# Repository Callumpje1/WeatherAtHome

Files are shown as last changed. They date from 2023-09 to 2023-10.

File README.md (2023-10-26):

# Weather at Home

Web application for displaying current climate data which is measured with a Wemos D1 Mini.

## Features

- Display current temperature and Humidity
- Add weather data for a given location
- Remove weather data for given location
- Plot chart for historic weather data
- Change temperature range via http

## Screenshots

### Homepage
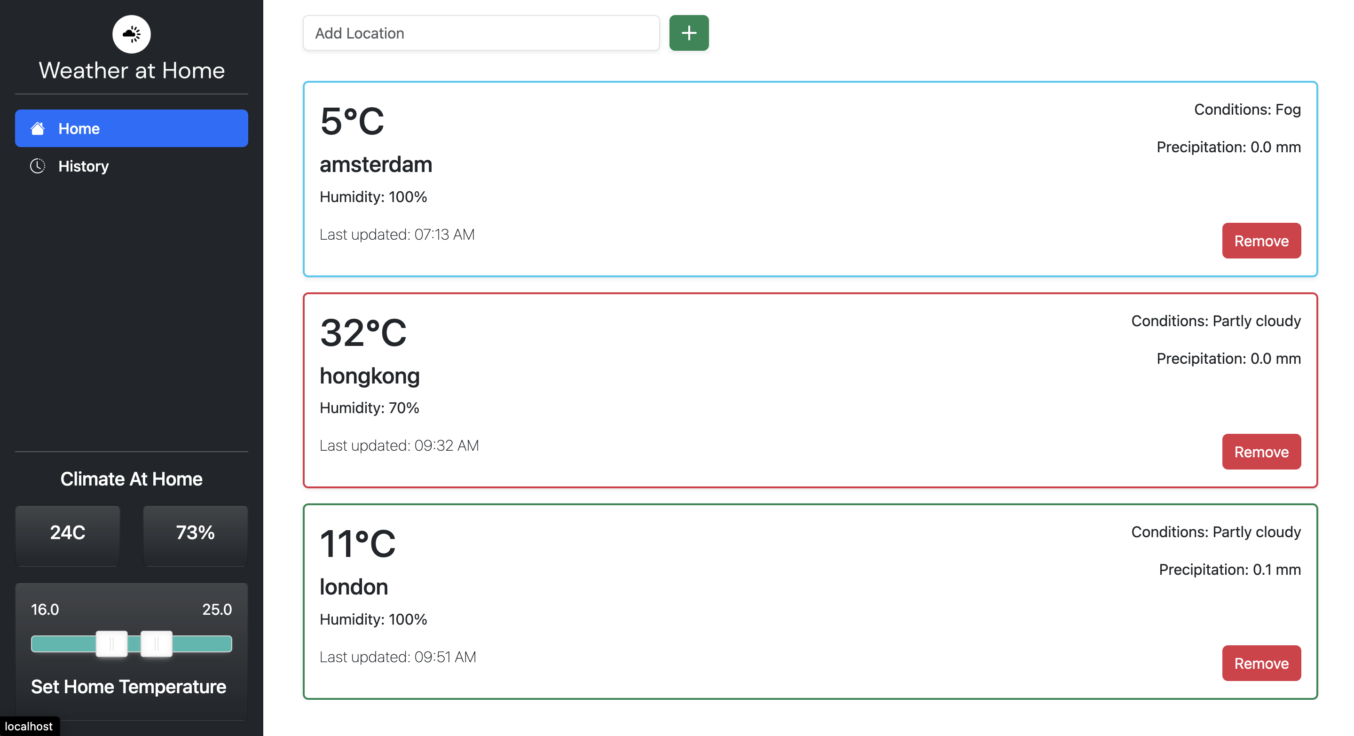
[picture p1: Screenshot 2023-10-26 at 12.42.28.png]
Homepage


### History
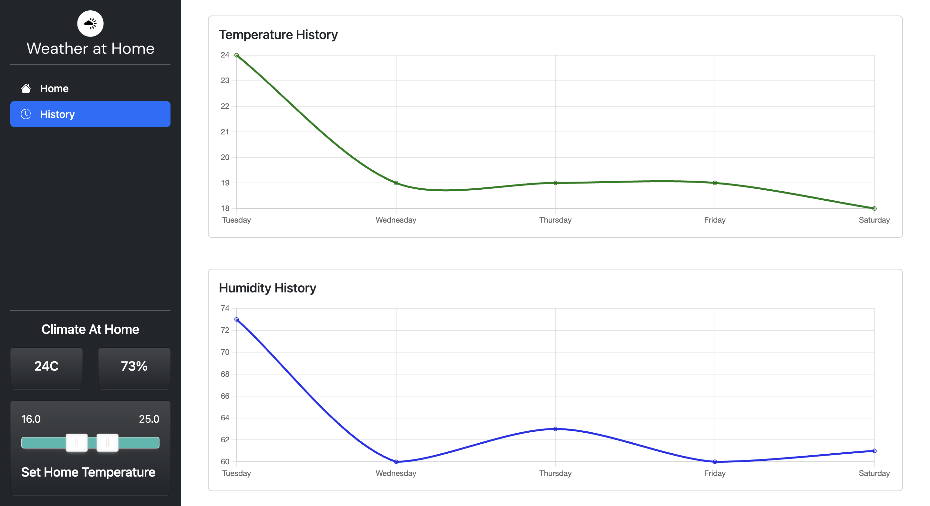
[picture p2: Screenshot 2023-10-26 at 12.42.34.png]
History


## Tech Stack

**Client:** C++ and Javascript

**Server:** Php

## Authors

- [@Callumpje1](https://www.github.com/Callumpje1)

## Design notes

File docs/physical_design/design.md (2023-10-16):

# Design

## Concept

### User and User Needs

At first i had chosen to make a star-wars themed weather station to appeal to the millions of star-wars fans around the world. However this concept showed to be a lot more complex to create then expected at first and didn't seem to work out the way i wanted it to. It was very hard to create a clear yoda character that would into eachtother without any glue. Due to these complications i chose to completely change my design.

Amsterdam, the city where i was born and where i have lived all my life. The city center has one thing that really stands out and is loved by most inhabitants of Amsterdam, the canal houses! These housed were built in the 17th century and where used for residences, storage units, and business during the dutch Golden Age. Nowadays these houses are some of the most expensive in the city meaning only the ultra rich can enjoy the design and heritage of the canal houses.
That's why i chose to create a weather station that resembles an Amsterdam canal house. This way anyone can own a small version of their favourite canal house at home.

### Goals of the Product

The goal of the product is to give everyone who loves the Amsterdam canal houses a chance to own their own one. This mini version is not only relevant due to the design that resembles the canal houses. A lot of the houses in Amsterdam, especially the older ones, don't have a reliable thermometer that gives the homeowners the information they need to be able to live in a comfortable temperature. That's why i chose to turn this mini canal house into a weather station. This weather station will give users the real-time temperature and humidity in their house. These values can be read out from a lcd screen by pressing a button. Next to the lcd screen the house will also have a led light which will give the user a color based on the temperature inside. This led light will change to red if it is too hot inside, green if the temperature is just right and blue when it's too cold inside.

### Requirements

In the below image you will see the requirements that i have set up for the physical design. The requirements contain some that are specific for the user that will use the product and some that are specific to the manufacturer of the product.

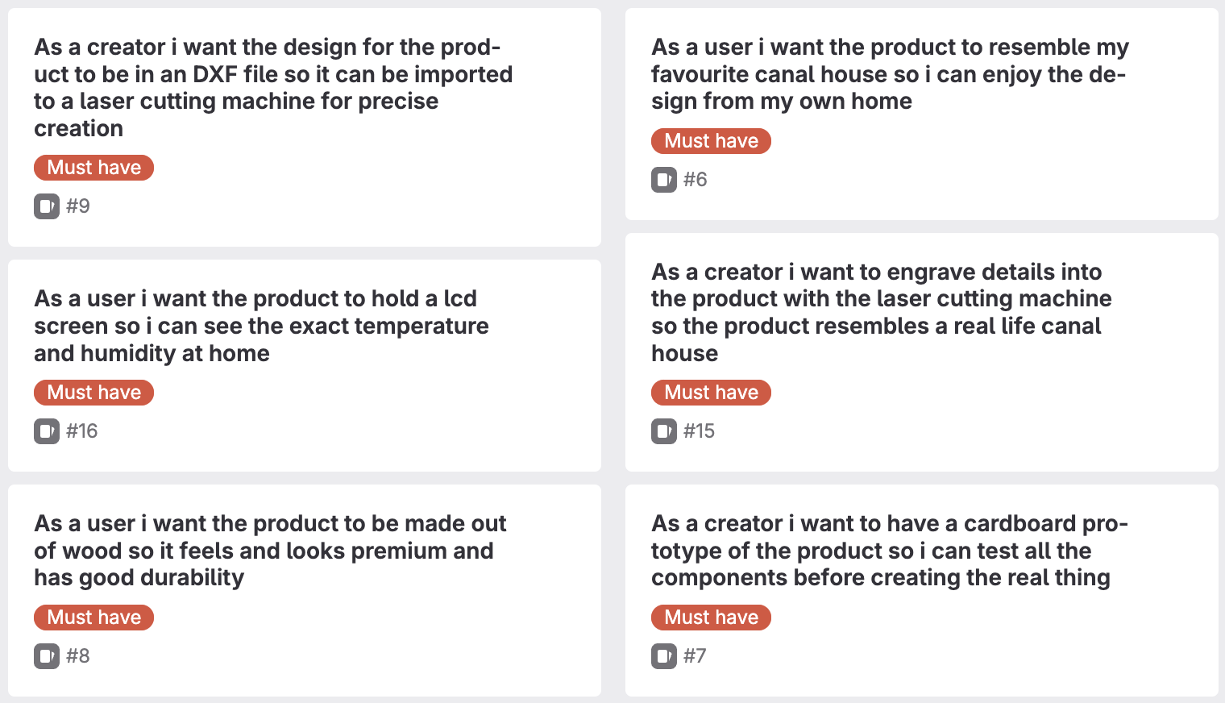
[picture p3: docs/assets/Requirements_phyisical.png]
Requirements Board Physical Design


### Sketches

Below you will find the sketch i created to get an idea for how the product will look. In the sketch i decided to draw the overall look of the house aswell as how the laser cut should look to be able to fit the parts together. The front face of the house will hold the lcd screen and button to control the screen for energy saving purposes. The display itself will display the current temperature and humidity within the users home. The top front of the house will have a windowd which will hold a rgb led. This led will change color based on the temperature. The color of the led will indicate that the user may need to decrease or increase the temperature in their home. The top of the box itself will have 4 slots that will be used to attach the roof. The slots will have a width of 5mm, this is the same thickness as the wood i want to use for the product. The sketch also shows some details like the shield at the top of the house and the front door. These details will be engraved into the product to give a premium and detailed look to the house.

 In the paper prototype i printed out the dxf version of my design to get an idea for how all the parts will fit into eachtother. After printing and cutting out the design i realised that i needed to be more precise when creating the slots for the roof. After this i made some changes to my dxf design in Inkscape to make the parts fit into eachtother perfectly.

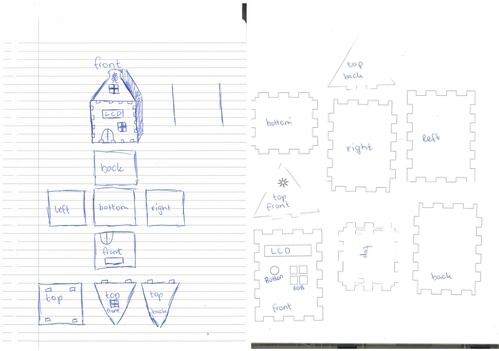
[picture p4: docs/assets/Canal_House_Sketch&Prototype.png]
Canal House Sketch & Paper Prototype


## Digital Manufacturing

### The Device

To create my desired design i will be using the BRM 6090 laser cutter which is available to us at the maker's lab. This machine has the possibility to cut and engrave materials with extreme precision. This machine keeps track of the material you are using and cuts accordingly, no need for measuring the distance of the laser to the material you are cutting. This makes it a lot easier to cut and engrave after eachother without changing the setup myself.

### The Material

I have chosen to create the canal house with 5mm mdf wood. I have chosen this material because it has a premium feel to it and i want my product to resemble the canal houses which are very expensive in real life. Also the material is very smooth and easy to work with. In my final design i don't only want to cut using the laser cutter, i also want to engrave and perhaps paint the surface so it comes as close as possible to a real canal house. For all these applications this wood suits the best. Also this wood fits together well when a right KERF is used to cut, this way the house can be assembled without glue.

## Digital Design

To Design the canal house i decided to first draw a sketch so i could get an idea of how i would create it. The first sketch is displayed in Sketches in a previous paragraphs. After drawing the sketch i decided to create a first prototype with paper to see if my design would work. To create the first prototype i used the Inkscape, this software is easy to use and can save a design in many file types that are supported by the laser cutting software: Lasercut. After recreating my sketch in Inkscape i printed the design on a A4 paper and cut it out to see if the concept would work. The paper prototype seemed like it would work. Because of this i decided to go to the Makerslab and laser cut the design to see what it would look. When laser cutting the design i realised that there were a couple of issues with my initial design. The way i had decided to create the house was not going to make it possible to attach a roof easily, which is essential for my design to work with the embedded device's LED. I had also not calculated the KERF of the machine correctly which meant the parts didn't fit together properly.

First design iteration

When creating the second iteration of my design i knew that i had to come up with a better way to design the roof and that i had to apply the right amount of KERF to make the pieces fit together seamlessly without glue.
So in my final iteration i created a different version of the roof by placing a inkscape node in the middle of my house and extending it to make a point that would resemble the roof, the roof has 2 finger slots to place the roof panels onto. I then measured the depth of the house to create the roofpanels with 2 slots on each side to connect to the slots in the house. By doing this i knew the roof would fit without too much effort.
In this iteration i also decided to place the window higher in the house to spread all components and make it feel more like a real house. When i started laser cutting my design i needed a couple of tries to figure out what the kerf of the laser cutter was. After doing a couple of miniature iterations and changing the thickness of the KERF i came to the conclusion that i needed to use a 0.400mm width to make the pieces fit together seamlessly

Couple of iterations

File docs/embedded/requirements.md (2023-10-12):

# Requirements

|Requirement ID#|Requirement|MoSCoW|Compliant|
|---|---|---|---|
|EMBRQ#01|Embedded device sends measured sensordata to the application backend over http or https.|Must|Yes|
|EMBRQ#02|Embedded device receives or retrieves status messages from the application backend over http or https.|Must|Yes|
|EMBRQ#03|Embedded device contains a dht-22 sensor to read temperature and humidity data|Must|Yes|
|EMBRQ#04|Embedded device contains a tactile button for switching the lcd's backlight on or off|Must|Yes|
|EMBRQ#05|Embedded device contains a rgb-module to display different colors based on the current temperature|Must|Yes|
|EMBRQ#06|Embedded device contains a 16x2 lcd for displaying current temperature and humidity|Must|Yes|
|EMBRQ#07|The embedded device uses the wifi manager for configuration of SSID, User ID (UID) en Password (PWD) for connecting to the network.|Must|Yes|

##EMBRQ#01
We start of with connecting to wifi with the ESP8266WiFi library by using our ssid and password. Then a variable is created for the endpoint in our php to which the data will be sent. We also add a delay timer so data is only sent once every 10 seconds. If the device connects to the wifi and is outside the timer delay we create a HTTP client using the ESP8266HTTPClient library. We then specify the content type to Json and create a JSON object with the temperature and humidity data which is collected from the temperature sensor. Then the json data is serialized into a JSON string and sent to the server via a HTTP POST request. 

Code:
```
#include <ESP8266WiFi.h>
#include <ESP8266HTTPClient.h>
#include <ArduinoJson.h>

const char *serverName = "http://rnuqm-145-28-186-143.a.free.pinggy.online/php/data_post.php";

unsigned long lastTime = 0;
unsigned long timerDelay = 10000;

void loop(){
  // Send an HTTP POST request every 10 seconds
  if ((millis() - lastTime) > timerDelay)
  {
    // Check WiFi connection status
    if (WiFi.status() == WL_CONNECTED)
    {
      WiFiClient client;
      HTTPClient http;

      // Domain name with URL path or IP address with path
      http.begin(client, serverName);

      // Specify content-type header
      http.addHeader("Content-Type", "application/json");

      // create a Json object
      DynamicJsonDocument doc(200);

      doc["temperature"] = dht.readTemperature();
      doc["humidity"] = dht.readHumidity();

      String jsonString;
      
      // Serialize the Json object
      serializeJson(doc, jsonString);

        // Post Json object to server
      http.POST(jsonString);

      // Disconnect
      http.end();
    }
    else
    {
      Serial.println("WiFi Disconnected");
    }
    lastTime = millis();
  }
}
```

##EMBRQ#02

[Insert text explaining how you fulfilled the requirement here]

Code:

##EMBRQ#03
Fulfilling this requirement was quite straightforward. We first include the DHT library and define the type of our dht sensor, which in my case is the dht22 and define the pin to which the sensor is connected. We then begin reading from the sensor with dht.begin(). In the loop we read the temperature and humidity from the sensor with the dht.readTemperature() or .readHumidity() functions. The functions inside the library already convert the raw voltage to temperature in celsius and humidity in a percentage. In the code below the values are only showed in the Serial monitor, in the final use case the data is sent to the php webserver.

Code:
```
#include <DHT.h>

#define DHTPIN 14
#define DHTTYPE DHT22
DHT dht(DHTPIN, DHTTYPE);

void setup() { 
    dht.begin();
}

void loop(){   
    double temperature = dht.readTemperature();
    double humidity = dht.readHumidity();

    Serial.print("Temperature: ")
    Serial.println(temperature)

    Serial.print("Humidity: ")
    Serial.println(humidity)
}

```

##EMBRQ#04
At the moment the button doesn't toggle the backlight on or off but all the functionalities are there for it. We first define our constant which is the pin where the button is connected and variables which will hold values to toggle the built in led from HIGH to LOW, when we start the led is switched on. We also define a debounce delay so the functionality of the button won't be affected by any noise. In the setup we define what we want to use the button and led for and turn the led on. In the loop we first read the state of the button and store it in a variable. If the button state has changed we reset the debounce timer. If the button changed to HIGH we also change the state of the led. This simulated how the button will turn the backlight of the lcd on or off based on the last state of the button. We then set the led to the correct state and save the last button state in our variable.

Code:
```
// Constants
const int buttonPin = 4;  

// Variables
int ledState = HIGH;
int buttonState;
int lastButtonState = LOW;

unsigned long lastDebounceTime = 0;  // the last time the output pin was toggled
unsigned long debounceDelay = 50;    // the debounce time; increase if the output flickers

void setup() {
  pinMode(buttonPin, INPUT);

  pinMode(LED_BUILTIN, OUTPUT);

  digitalWrite(LED_BUILTIN, ledState);
}

void loop() {
  // read the state of the switch into a local variable:
  int reading = digitalRead(buttonPin);

  // If the switch changed, due to noise or pressing:
  if (reading != lastButtonState) {
    // reset the debouncing timer
    lastDebounceTime = millis();
  }

  if ((millis() - lastDebounceTime) > debounceDelay) {
    // if the button state has changed:
    if (reading != buttonState) {
      buttonState = reading;
      // only toggle the LED if the new button state is HIGH
      if (buttonState == HIGH) {
        ledState = !ledState;
      }
    }
  }

  // set the LED:
  digitalWrite(LED_BUILTIN, ledState);

  // save the reading, it'll be the lastButtonState:
  lastButtonState = reading;
}
```

##EMBRQ#05
We first define the pins to which the red,blue and green wires of the rgb module are connected. In our setup we define what we want to use the pins for, in this case all pins will be used for output. In the loop we read the temperature data from the DHT-22 sensor and base the color of our rgb module on the current temperature conditions. A cold temperature turns the led blue, a comfortable temperature turns the led greend and a hot temperature turns the led to red. The color of the led is changed by determining the amount of red,green and blue we want the led to show.

Code:
```
#include <DHT.h>

// Variables

int redpin = 14;
int bluepin = 13;
int greenpin = 12;

void setup() {
  pinMode(redpin, OUTPUT);
  pinMode(bluepin, OUTPUT);
  pinMode(greenpin, OUTPUT);
}

void loop() {
    // Store dht temperature data
    temp = dht.readTemperature();

    // Update rgb color based on temperature
    if (temp<18){
    analogWrite(redpin, 0);     // No red
    analogWrite(bluepin, 255);  // Full intensity blue, no green
    analogWrite(greenpin, 0);   // No green
    } else if (temp >18 && temp<25){
    analogWrite(redpin, 0);     // No red
    analogWrite(bluepin, 0);    // No blue
    analogWrite(greenpin, 255); // Full intensity green, no red or blue
    } else {
    analogWrite(redpin, 255);   // Full intensity red, no green or blue
    analogWrite(bluepin, 0);    // No blue
    analogWrite(greenpin, 0);   // No green
  }
}
```

##EMBRQ#06
Embedded device contains a 16x2 lcd for displaying current temperature and humidity

Code:
[Insert code snippet proving the requirement is fulfilled here]

##EMBRQ#07
We first define our network's ssid and password to connect to. In the setup of our code we attempt to connect to the network with the ESP8266WiFi Library using WiFi.begin() with our ssid and password variables. We then give the user feedback via the Serial monitor to let them know if we are connected, if we are connected the current IP address will be showed to the user.

Code:
```
#include <ESP8266WiFi.h>

const char *ssid = "iotroam";
const char *password = "8iuZwH958F";

void setup()
{
    // Attempt to connect to the Wi-Fi network
    WiFi.begin(ssid, password);
    Serial.println("Connecting");
  
    // Wait for the connection to be established
    while (WiFi.status() != WL_CONNECTED)
  {
    delay(500);
    Serial.print(".");
  }
  
    Serial.println("");
    Serial.print("Connected to WiFi network with IP Address: ");
    Serial.println(WiFi.localIP());
}
```

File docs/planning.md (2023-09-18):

# Project Planning
On this page you will find the user stories and their corresponding topic and relevance. This will be a guideline for which components will have to be finished at the end of this period. Also a weekly planning is added that gives a more detailed look at which aspects i am going to be completing daily.

# User Stories
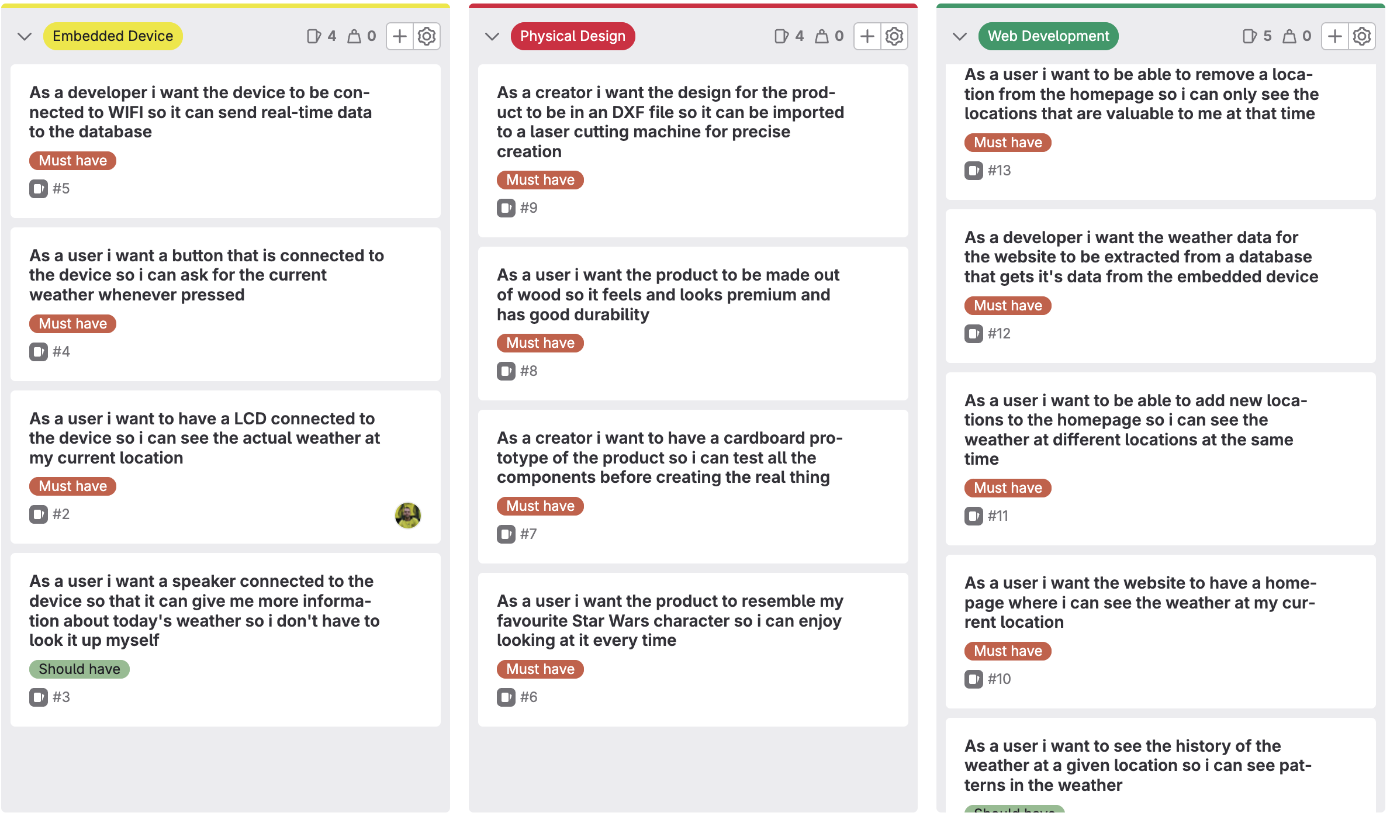
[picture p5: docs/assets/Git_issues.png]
Git issues board


# Weekly Planning
| Week | Physical Design | Web Development | Embedded Device |
|---|---|---|---|
| 1 | First sketch of product | Creating homepage layout | Adding temperature sensor to device |
| 2 | Making first cardboard prototype | Creating database | Adding LCD screen to device |
| 3 | Creating SCAD for protoype | Retrieving data from database | Sending data to database |
| 4 | Creating first wooden prototype | Adding more functionalities to webapp | Adding button to device |
| 5 | Working on wooden prototype | Refactoring webapp | Adding speaker to device |
| 6 | Assembling wooden prototype | Adding could have functionalities | Refactoring |
| 7 | Market research | Market research | Market research |
| 8 | Time for could haves | Time for could haves | Time for could haves |

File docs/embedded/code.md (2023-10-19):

# Embedded code

## LM35 Temperature Sensor

During my first encounter with the Wemos D1 I was able to connect the LM35 Temperature sensor so i can read out the current temperature. To Achieve this i needed to read the raw analog voltage from the sensor. Next the raw voltage had to be converted to millivolts so that a represantable temperature value could be calculated. [See Code Here](https://gitlab.fdmci.hva.nl/IoT/2023-2024-semester-1/individual-project/iot-svadkoc/-/blob/8bd7aae81da8f2acf82b724e639a5dfc17b77f98/embedded/wemos-temperature/Temper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)

## Tactile Button

The second part of working with the Wemos D1 was figuring out how to connect a button to the microcontroller so the user can control when the temperature is shown. To do this i had to connect a 10k Ohm resistor to the button so i could be ablo to read the button state and debounce the button when needed. The code for this part was quite simple. First the input pin for the button is declared. Then I keep track of the led and button state with a declared variable so we know in which state they are and can change them accordingly. I also added a buffer to prevent changes by noise. The code reads the current state of the button and changes the built-in led accordingly. [See Code Here](https://gitlab.fdmci.hva.nl/IoT/2023-2024-semester-1/individual-project/iot-svadkoc/-/blob/main/embedded/Button_sketch/Button_sketch.ino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)

## DHT-22 Sensor

After making progress in the other slices of the project i realised the LM35 temperature sensor wouldn't give me enough data to crowd my webapplication. That's why i chose to purchase a DHT-22 sensor that can not only measure the temperature but also gives a humidity percentage. This way i can give the user more information about the conditions inside their house. Setting up the DHT-22 was quite straightforward. After wiring up the sensor we add the dht library and declare the type of pin and where the pin is connected to the Wemos D1 mini. Afterwards we start the dht sensor with dht.begin(). In the loop we read the current temperature in celsius and the humidity with dht.readTemperature() and dht.readHumidity() and write them to the Serial monitor. [See Code Here](https://gitlab.fdmci.hva.nl/IoT/2023-2024-semester-1/individual-project/iot-svadkoc/-/blob/main/embedded/Dht-22/Dht-22.ino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)

## KY-016 RGB Module

The next part to add to the embedded device is the rgb-led module. This rgb light will change colors based on the current temperature. To get the rgb led working properly we first define to which pins the red,blue and green connectors are attached. Afterwards we set the pin mode for each of the colored pins, in this case they are all used as outputs. In the loop we check the temperature and display a different color on the led based on the temperature. To change the led color we adjust the amount of each color that is displayed to get the desired color. In my case i only need full brightness red, blue and green so no need to mix colors. [See Code Here](https://gitlab.fdmci.hva.nl/IoT/2023-2024-semester-1/individual-project/iot-svadkoc/-/blob/main/embedded/Rgb_led/Rgb_led.ino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)

## 1602 LCD

The final part that has to be added to the embedded device is the 16x2 Lcd display to show the user what the current temperature and humidity is inside their house. To get the Lcd working we first include the LiquidCrystal i2c library so our Wemos D1 Mini can communicate with the display. In the setup we initialize the display and turn the backlight on. In the loop we read the conditions from the dht-22 sensor. If the values change the text on the display also changes accordinly, this way the display doesn't update when the temperature or humidity doesn't change, we save the last readings in a variable so we can check it in the next loop.  [See Code Here](https://gitlab.fdmci.hva.nl/IoT/2023-2024-semester-1/individual-project/iot-svadkoc/-/blob/main/embedded/Rgb_led/Rgb_led.ino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)

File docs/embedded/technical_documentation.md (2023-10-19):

# Technical documentation

## Wiring Diagram

Below you will find the Wiring diagram for the embedded device, created in Fritzing. This wiring diagram is a visual representation of the connections i have made within the system. It helps other technicians to understand and recreate the system that i have created. By using labels on any part that isn't labelled by itself we can make a very clear overview of the structure. Also we are able to test the connections withing the fritzing software which can be a handy way to find an issue before putting parts together physically.

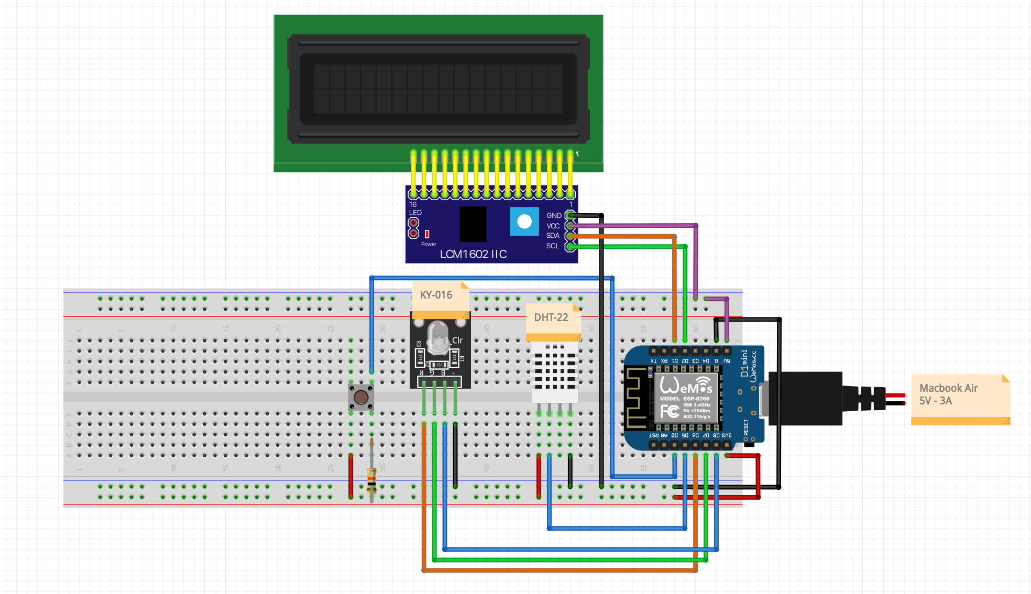
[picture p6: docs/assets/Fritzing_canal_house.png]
Fritzing Wiring Diagram


## Bill of Materials (BOM)

The Bill of Materials is a list of all the components used for creating the embedded device. It contains each components part number, manufacturer, description, quantity used, price (before and after VAT) and a URL to find the component. It is another method to give others a clear overview of the components that are used for creating the embedded device. In some cases i couldn't find the exact manufacturer and use Generic as the manufacturer.

| Part number | Manufacturer | Description | Quantity | Price (incl VAT) | Subtotal (incl VAT) | Example URL |
|---|---|---|---|---|---|---|
| WMD1MINIV4 | Wemos | Wemos D1 Mini V4 | 1 | 4.95 EUR | 4.95 EUR | [Wemos D1 Mini](https://www.hobbyelectronica.nl/product/d1-mini-usb-c-v4/) |
| COM-KY016RGBLED | Generic | KY-16 RGB LED Module | 1 | 1.79 EUR | 2.79 EUR | [KY-016 RGB](https://tecvoordeel.nl/product/rgb-led-module/) |
| C-DHT22  | DHT | DHT-22 Sensor | 1 | 5.50 EUR | 5.50 EUR | [DHT-22 sensor](https://www.tinytronics.nl/shop/nl/sensoren/lucht/vochtigheid/dht22-thermometer-temperatuur-en-vochtigheids-sensor) |
| OT2021 | OTRONIC | I2C Backpack | 1 | 1.10 EUR | 1.10 EUR | [I2c backpack](https://www.otronic.nl/nl/lcd-1602-2004-i2c-adapter.html) |
| LCD1602 | OTRONIC | 1602 LCD Display | 1 | 2.36 EUR | 2.36 EUR | [1602 Lcd](https://www.otronic.nl/nl/1602-lcd-groen-geel-met-backlight.html) |
| 101-TS6111T1601-EV| Generic | Tactile Button | 1 | 0.06 EUR | 0.06 EUR | [Tactile button](https://www.hackerstore.nl/Artikel/177) |

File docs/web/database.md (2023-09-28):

# Database

I have chosen to use two tables in my database. The Weather table represents the current weather measurement with the corresponding time and date and several temperature related values like: temperature, humidity and windspeed. Also an auto generated id is added to each reading. The Weather History table has a foreign key which is linked to the real-time temperature table, this way the weather history table doesn't have to store reduntant values. The tables have a one to many relationship because there can only be one current weather reading at a time, the weather history table however can have multiple readings.

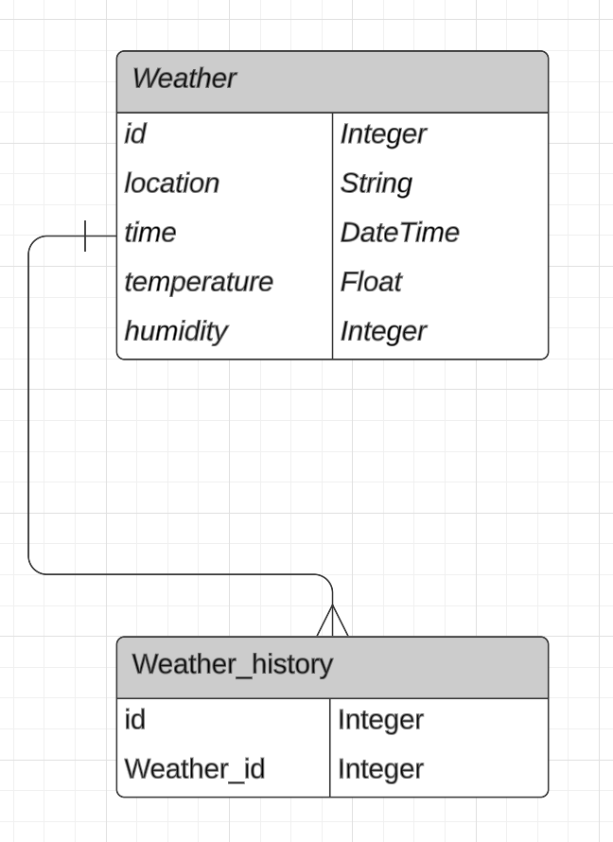
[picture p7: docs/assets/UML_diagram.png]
UML_diagram


I asked Mats for feedback on my initial UML diagram before i would make it in SQL Workbench. In the feedback i mainly got feedback on the use of the weather history table, this table was unnecessary due to the use of time in the regular weather table. By using SQL functions i will be able to sort and filter the weather as needed. Below is the updated version database in MySQL Workbench. In the below example i have removed the history table.

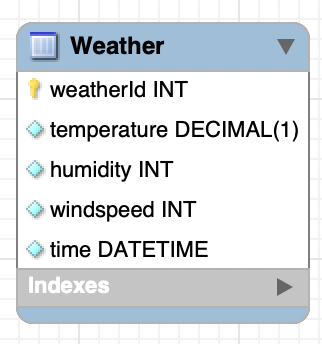
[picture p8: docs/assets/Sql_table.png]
SQL_table


After making the database in MySqlWorkbench and inserting data into the database i realised there was still one issue with my database. I had used the DECIMAL(1) for the temperature column. This meant that only values with 1 digit could be inserted which is incorrect. When creating the final database design i changed the value of temperature from DECIMAL(1) to INT so it would be possible to add round temperature's as available in the API. Below you will find the final design for my database with a link to the insert script. The insert script creates the database: weather. Inside this database you will find a auto-generated id that is generated with each insert. The temperature, humidity and windspeed which are all integers. The date column is also auto-inserted, this will add the current date with each new insert.

Create_Script

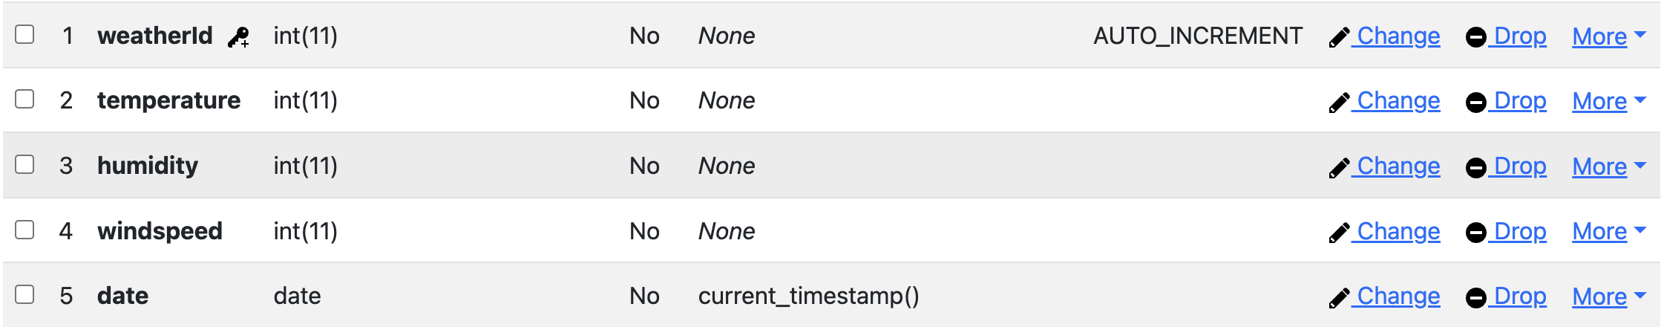
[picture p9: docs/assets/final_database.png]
Final_Database


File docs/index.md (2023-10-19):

# Weather at Home

Describe the purpose of your blueprint. Design a nice front-page image that will describe your product.

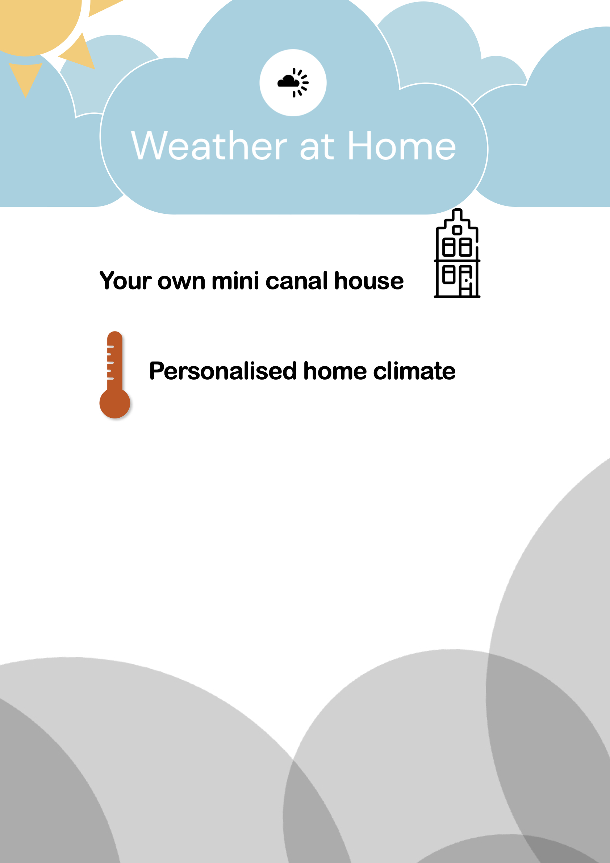
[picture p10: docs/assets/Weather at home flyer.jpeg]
Weather at Home flyer


{{ mdocotion_header('https://images.unsplash.com/photo-1550745165-9bc0b252726f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') }}

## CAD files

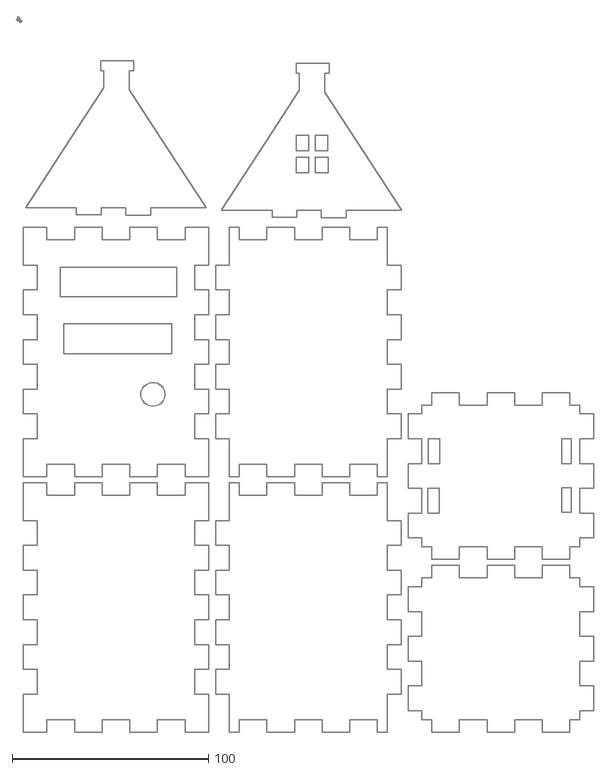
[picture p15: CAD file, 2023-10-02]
docs/assets/Canal_House.dxf
294.2 x 364.9

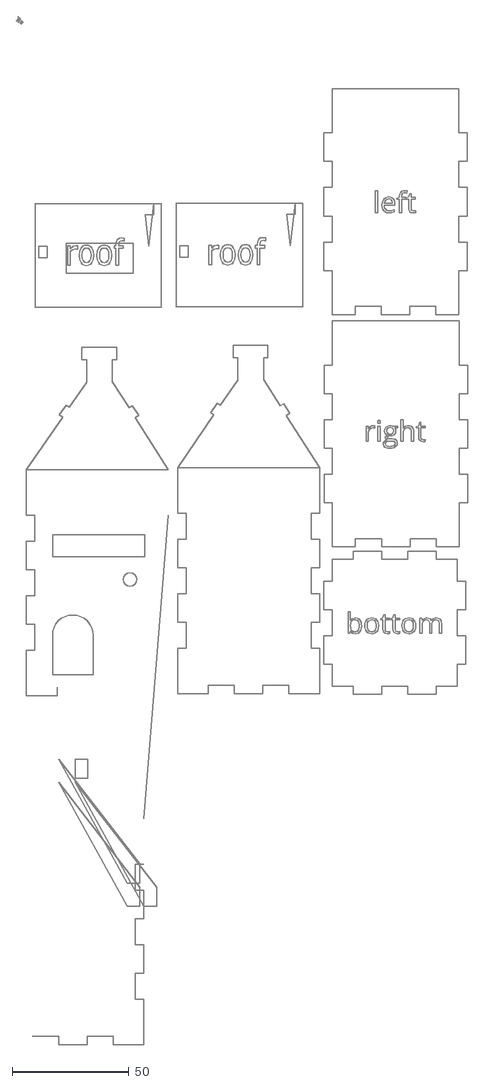
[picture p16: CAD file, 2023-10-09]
physical_design/House with roof.dxf
193.4 x 440.8

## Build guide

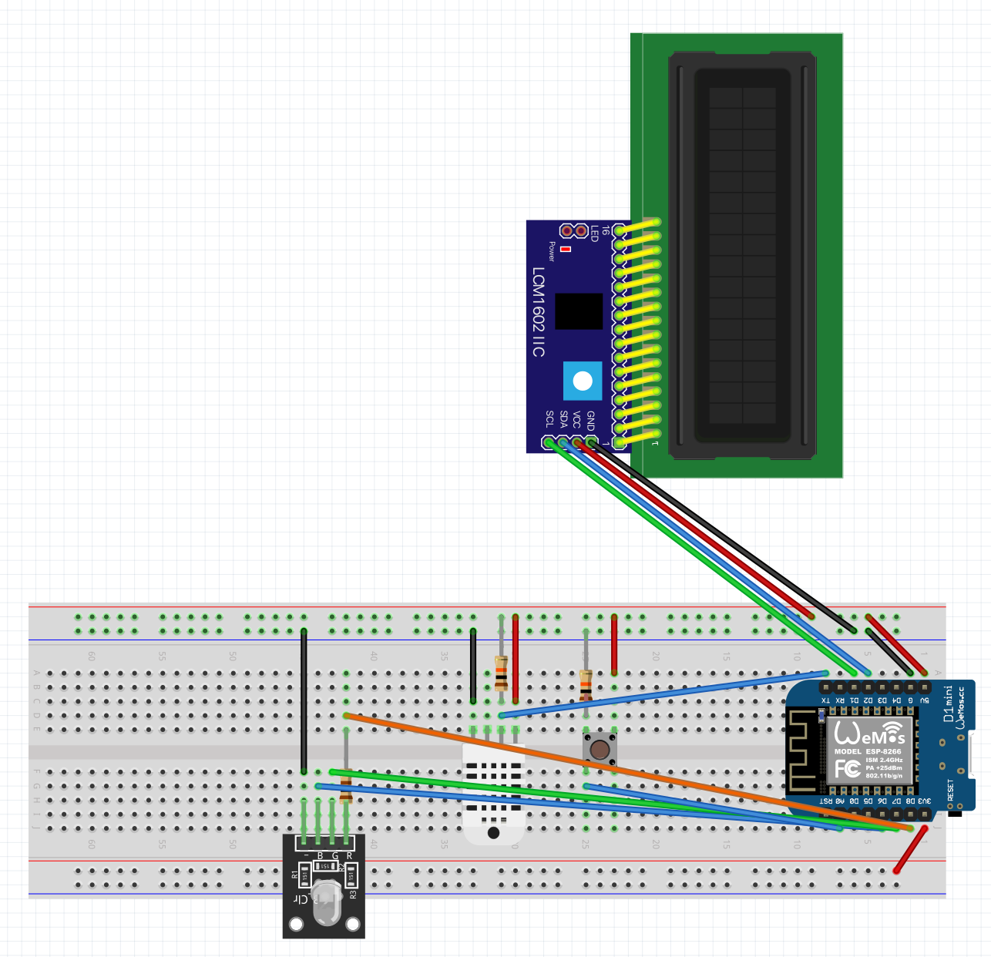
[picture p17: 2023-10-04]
docs/assets/Wiring_Diagram.png

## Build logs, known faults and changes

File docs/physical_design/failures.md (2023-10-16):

# Failures

During my first encounter with the laser cutting machine i ran into some issues whit the design i had chosen. The design i wanted to use was way too detailed and didn't create the type of casing that would be able to hold the embedded device. In my next iteration i will decrease the amount of detail in the design. However i have learned more about working with the laser cutter which means i will need less time next time working with the machine. And i had also got some experience working with Inkscape and Laserwork which i would use when creating my next iterations. 

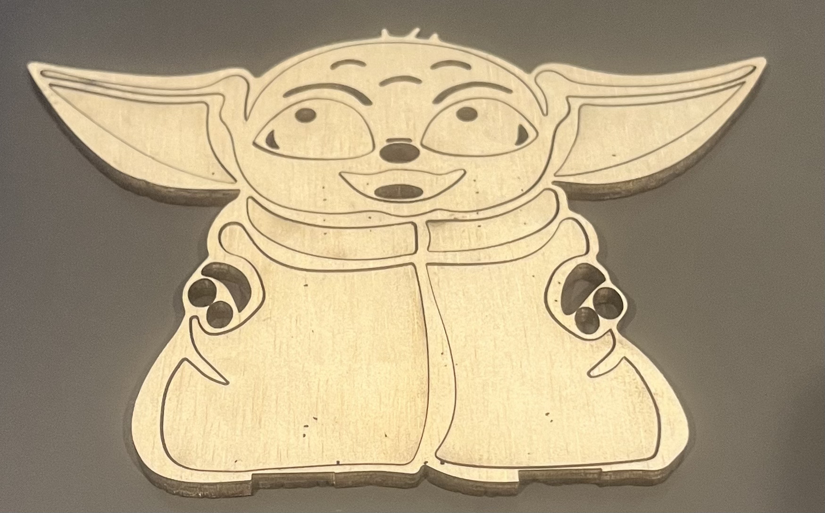
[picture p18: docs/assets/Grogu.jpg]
Grogu first laser cut


After some time trying to figure out the detailed design for Grogu i decided to leave the design and think up a new product to case my embedded device. After some thinking i came up with the idea to create a miniature canal house.
When creating the first iteration of my new design i had an idea on how to create the roof for my house. However this design had some flaws and didn't work out the way i had imagined it. The roof didn't fit onto the design correctly and didn't contain roof panels to close the design. This part was essential because i wanted to add a LED module behind the window, this wouldn't work if the roof was open. When i was creating the paper prototype i didn't plan to put the led inside the roof, at first i just wanted it inside the house. However when i created the prototype on the laser cutter i realised that it would look a lot nicer if the components were spread out. This meant the house had to be redesigned to fix the issues. 

First version of canal house

After fixing the intital issues of my design it was time to upload the file to the laser cutter and get working. When the laser cutter was finished it looked like the new design had worked. The roof now contained the right slots to hold the roofpanels and all components were spaced out correctly. However when trying to put the prototype together i realised that the house didn't fit together correctly, there was too much space inbetween the slots meaning they didn't fit together correctly. After doing some research i realised the laser cutter has an amount of material that it cuts away when creating a design, this is called Kerf. To make the pieces fit together snug i needed to take the right amounnt of Kerf into account. In my next two iterations i tested different amounts of Kerf-width to figure out how much i needed to apply. After the second minitature iteration i had found out the laser cutter had a kerf of 0,15mm. When adding this amount to the width of my borders the pieces should fit together perfectly.

Versions of canal house with different Kerf

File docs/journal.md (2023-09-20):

# Learning journal
During the first week of the Minor i had some issues with coming to all the classes due to work. I wasn't able to do as much as i had wanted to do and this meant i got a below average for my very first performance review, not a good start. In the upcoming weeks i have sorted the situation with work and am going to make sure to do get back up to speed on the minor. 

I have been able to spend more time on the project during week 2. On monday i was able to setup my issues board on Git to get my user stories sorted. This way i am also able to make a more specific project planning for the upcoming weeks, which will help me a lot. On this day i was also able to setup the Chart.js library which i will be using to show historic weather data to the user. I had some issues with connecting the LCD display, I will one of my fellow students if they can help me with this issue the very next workday.

On Wednesday i had a bad night sleep due to my son waking up very early. Because of this i didn't spend my time very efficiently. I created the SQL database in workbench and I spent a lot of time figuring out how to get a button connected to the Wemos D1 mini. Unfortunately I still have not got it to work like i would want it to. I will ask one of my fellow students if they can help me figure out the issue i am having.

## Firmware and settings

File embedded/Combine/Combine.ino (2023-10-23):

#include <LiquidCrystal_I2C.h>
#include <DHT.h>
#include <ESP8266WiFi.h>
#include <ESP8266HTTPClient.h>
#include <ESP8266WebServer.h>
#include <WiFiClient.h>
#include <ArduinoJson.h>

// Constants won't change.
#define DHTPIN 14
#define DHTTYPE DHT22
DHT dht(DHTPIN, DHTTYPE);

// Set web server port number to 80
ESP8266WebServer webserver(80);

const char* ssid = "RM";
const char* password = "Bellum97!";

const char* serverName = "http://rnuhl-178-84-238-34.a.free.pinggy.online/php/post_measured_data.php?";

const int buttonPin = 2;  // the number of the pushbutton pin
int redpin = 12;          // select the pin for the red LED
int bluepin = 15;         // select the pin for the blue LED
int greenpin = 13;        // select the pin for the green LED

// Variables will change:
bool lcdState = true;         // Start with the LCD in the ON state
bool lastButtonState = HIGH;  // the previous reading from the input pin

unsigned long lastDebounceTime = 0;
unsigned long debounceDelay = 50;  // Adjust this value as needed

unsigned long lastTime = 0;

unsigned long timerDelay = 300000;

// Global variables for min and max temperature
double minTemp = 18.0;
double maxTemp = 24.0;

double lastTemperature = 0.0;  // Initialize with an out-of-range value
double lastHumidity = 0.0;     // Initialize with an out-of-range value

// Define the LCD
LiquidCrystal_I2C lcd(0x27, 16, 2);

// Function to map temperature to RGB colors
void mapTemperatureToRGB(double temp) {
  if (temp < minTemp) {
    analogWrite(redpin, 0);     // No red
    analogWrite(bluepin, 255);  // Full intensity blue, no green
    analogWrite(greenpin, 0);   // No green
  } else if (temp > minTemp && temp < maxTemp) {
    analogWrite(redpin, 0);      // No red
    analogWrite(bluepin, 0);     // No blue
    analogWrite(greenpin, 255);  // Full intensity green, no red or blue
  } else {
    analogWrite(redpin, 255);  // Full intensity red, no green or blue
    analogWrite(bluepin, 0);   // No blue
    analogWrite(greenpin, 0);  // No green
  }
}

void handleData() {
  // Check if the HTTP method is POST
  if (webserver.method() == HTTP_POST) {
    // Parse the JSON data
    String json = webserver.arg("plain");
    DynamicJsonDocument doc(256);  // Adjust the JSON buffer size accordingly
    DeserializationError error = deserializeJson(doc, json);

    if (error) {
      // Error parsing JSON
      webserver.send(400, "application/json", "{ \"error\": \"Parsing Json error\" }");
    } else {
      // JSON parsed successfully
      minTemp = doc["minTemp"];
      maxTemp = doc["maxTemp"];

      webserver.send(200, "application/json", "{\"message\": \"Data received and processed successfully\"}");
    }
  }
}

void setup() {
  // Enable the internal pull-up resistor on the button pin
  pinMode(redpin, OUTPUT);
  pinMode(bluepin, OUTPUT);
  pinMode(greenpin, OUTPUT);
  pinMode(buttonPin, INPUT_PULLUP);

  Serial.begin(9600);  // Initialize serial communication

  WiFi.begin(ssid, password);
  Serial.println("Connecting");
  while (WiFi.status() != WL_CONNECTED) {
    delay(500);
    Serial.print(".");
  }
  Serial.println("");
  Serial.print("Connected to WiFi network with IP Address: ");
  Serial.println(WiFi.localIP());

  // Start Web Server
  webserver.on("/range", HTTP_POST, handleData);

  webserver.begin();

  lcd.init();       // Initialize the LCD
  lcd.backlight();  // Turn on the backlight
  lcd.setCursor(0, 0);
  lcd.print("Welcome");
  dht.begin();
  delay(2000);
  lcd.clear();
}

void loop() {
  webserver.handleClient();

  // Read the state of the switch into a local variable:
  bool buttonState = digitalRead(buttonPin);

  if (buttonState != lastButtonState) {
    // Check if the button state has changed
    if ((millis() - lastDebounceTime) > debounceDelay) {
      if (buttonState == LOW) {
        lcdState = !lcdState;  // Toggle the LCD state
        if (lcdState) {
          lcd.backlight();
        } else {
          lcd.noBacklight();
          lcd.off();
        }
      }
      lastDebounceTime = millis();
    }
    lastButtonState = buttonState;
  }

  // Read temperature and humidity
  double temp = dht.readTemperature();
  double hum = dht.readHumidity();

  mapTemperatureToRGB(temp);

  // Only update the LCD when temperature or humidity changes
  if (temp != lastTemperature || hum != lastHumidity) {
    lcd.setCursor(0, 0);
    lcd.print("Temp: ");
    lcd.print(temp, 1);  // Display 1 decimal place
    lcd.print("C");

    lcd.setCursor(0, 1);
    lcd.print("Humidity: ");
    lcd.print(hum, 1);  // Display 1 decimal place
    lcd.print("%");
    lastTemperature = temp;
    lastHumidity = hum;
  }

  // Send an HTTP POST request every 5 minutes
  if ((millis() - lastTime) > timerDelay) {
    // Check WiFi connection status
    if (WiFi.status() == WL_CONNECTED) {
      WiFiClient client;
      HTTPClient http;

      // Your Domain name with URL path or IP address with path
      http.begin(client, serverName);

      // Specify content-type header
      http.addHeader("Content-Type", "application/json");

      // create a Json object
      DynamicJsonDocument doc(256);

      doc["temperature"] = temp;
      doc["humidity"] = hum;

      String jsonString;

      serializeJson(doc, jsonString);

      http.POST(jsonString);

      // Disconnect
      http.end();
    } else {
      Serial.println("WiFi Disconnected");
    }
    lastTime = millis();
  }
}

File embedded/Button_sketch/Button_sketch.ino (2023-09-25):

// constants won't change. They're used here to set pin numbers:
const int buttonPin = 4;  // the number of the pushbutton pin
const int temperaturePin = 5; // the number of the temperature sensor output pin

// Variables will change:
int ledState = HIGH;        // the current state of the output pin
int buttonState;            // the current reading from the input pin
int lastButtonState = LOW;  // the previous reading from the input pin

// the following variables are unsigned longs because the time, measured in
// milliseconds, will quickly become a bigger number than can be stored in an int.
unsigned long lastDebounceTime = 0;  // the last time the output pin was toggled
unsigned long debounceDelay = 50;    // the debounce time; increase if the output flickers

void setup() {
  Serial.begin(9600);

  pinMode(buttonPin, INPUT);

  pinMode(LED_BUILTIN, OUTPUT);

  digitalWrite(LED_BUILTIN, ledState);
}

void loop() {
  // read the state of the switch into a local variable:
  int reading = digitalRead(buttonPin);

  int rawvoltage = analogRead(temperaturePin);

  // Convert the raw voltage to millivolts (LM35 outputs 10 mV per degree Celsius)
  float millivolts = (rawvoltage / 1024.0) * 3300;
  
  // Convert millivolts to degrees Celsius
  float celsius = millivolts / 10;
  
  Serial.println(rawvoltage);
  Serial.println(celsius);

  // If the switch changed, due to noise or pressing:
  if (reading != lastButtonState) {
    // reset the debouncing timer
    lastDebounceTime = millis();
  }

  if ((millis() - lastDebounceTime) > debounceDelay) {
    // whatever the reading is at, it's been there for longer than the debounce
    // delay, so take it as the actual current state:

    // if the button state has changed:
    if (reading != buttonState) {
      buttonState = reading;
      // only toggle the LED if the new button state is HIGH
      if (buttonState == HIGH) {
        ledState = !ledState;
      }
    }
  }

  // set the LED:
  digitalWrite(LED_BUILTIN, ledState);

  // save the reading. Next time through the loop, it'll be the lastButtonState:
  lastButtonState = reading;
}

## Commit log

2023-09-11 Embedded Device
    Added the sketch for connecting the Wemos D1 to Wifi. First SSID and Password are defined before running a loop to check for connection. Blink LED when connection has been established.
2023-09-11 Embedded Device
    Connected LM35 temperature sensor to Wemos D1. Reading temperature in Celcius.
2023-09-11 Portfolio
    Explanation of the work i have done on the embedded device.
2023-09-14 Web
    Created cards to display the current temperature at the given locations.
2023-09-25 Physical design
    Created svg and dxf design for laser cutting first prototype
    [Grogu.dxf]
2023-09-25 Button with debounce function to switch built-in led voltage from high to low
2023-09-25 Portfolio
    Added description on connecting a button to the Wemos D1 with debounce function
2023-09-28 Web
    Insert weather data into sql database with php
2023-09-29 Embedded Device
    Created sketch for connecting to php api and doing post request to send temperature data
2023-09-29 Web
    Plotted weather history chart with date and temperature average from sql database
2023-10-02 Portfolio
    Written the sketches for physical design and added image of my own sketch
    [Canal_House.dxf]
2023-10-02 Physical Design
    Sketch and first paper prototype files created and added
2023-10-02 Physical Design
    Dxf file created for laser cutting
    [Canal_House.dxf]
2023-10-04 Embedded Device
    Connected the dht 22 temperature/humidity sensor
2023-10-04 Embedded Device
    Ky16 rgb led connected and working with temperature logic
2023-10-04 Embedded Device
    The rgb led is now controlled with the temperature sensor
2023-10-04 Refactor
    Clear overview for folders
    [Forcecast Sketch.fzz, Grogu.dxf]
2023-10-05 Embedded Device
    Sending temperature data in Json object to api
2023-10-05 Web
    Http post request to send min and max temperature range to server for use on the wemos d1
2023-10-06 Web
    Javascript functions for displaying temperature data on frontend
2023-10-06 Web
    Php file created for getting average humidity and displaying current temperature and humidity values
2023-10-09 House lasercutting design with 0,5 kerf
    [House with roof.dxf]
2023-10-09 Physical Design
    Created house design with 0,3cm kerf
2023-10-11 Web
    Updated php for getting average temperature values from sql database
2023-10-12 Portfolio: Requirements for embedded device
    Added requirements list for embedded device with code examples
2023-10-12 Portfolio: added material and device information
2023-10-16 Portfolio: Fritzing and BOM added to technical documentation
2023-10-16 Portfolio: Fritzing and BOM final text added
2023-10-16 Revert "Portfolio: Fritzing and BOM final text added"
    This reverts commit 2e80bfa384eb91b981bd39dcdb52fb9c3764c89a.
    # Conflicts:
    # docs/.pages
    [Forcecast Sketch.fzz]
2023-10-16 Portfolio: embedded wiring & bom fix
2023-10-19 Physical Design: test hinges to test the offset and kerf
2023-10-19 Web: Php for posting temperature range to wemos d1 mini
2023-10-23 Embedded device: wifiserver for receiving http request from php
2023-10-23 Embedded Device: combined all code
2023-10-23 Web: Created temperature range with dual selector
2023-10-23 Web: Php file for sending temperature range
